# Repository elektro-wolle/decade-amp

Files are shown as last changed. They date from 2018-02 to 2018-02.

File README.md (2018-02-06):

# Selectable Decade Amplifier

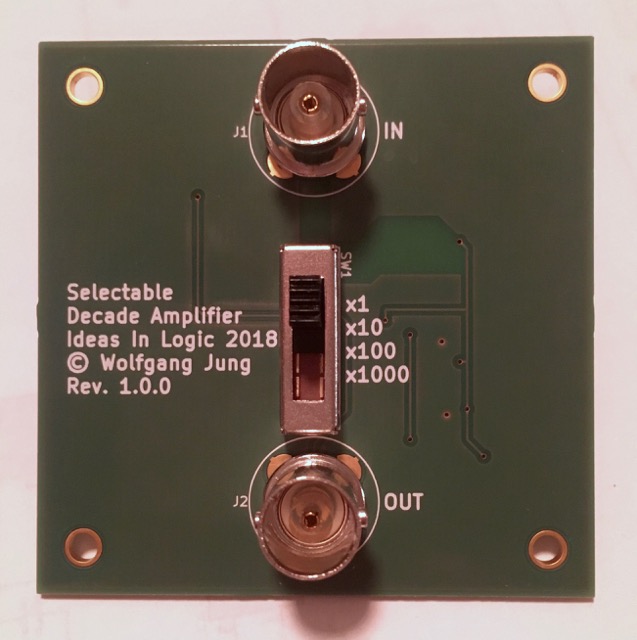
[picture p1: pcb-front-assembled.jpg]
Front


Due to my - in the highest sensitive ranges - a little bit noisy Rigol DS-1054z scope, I decided to provide a small pre-amplifier for low-voltage measurements (a.k.a. electret microphone signals, shunt-voltages, etc.).
For best performance in the micro-volt range, a dual stage amplifier (both stages provide 10V/1V gain) is built with the [MCP6V27](http://www.microchip.com/wwwproducts/en/MCP6V27). A third and last stage gives the final 10V/1V amplification resulting in a gain of 1000V/1V with a 3db cut-off at ~200 kHz.

For the third stage and the virtual ground a cheaper [MCP6292](http://www.microchip.com/wwwproducts/en/MCP6292) is used.

**The input voltage must not exceed ±1.5V!**

Current consumption should be ~1.6mA, the CR2032 coin-cell should last about 200h. The slide-switch disables the op-amps, if 1V/1V is selected.

Further improvements:
*  TVS-Diodes for clamping input voltage?

## Schematic
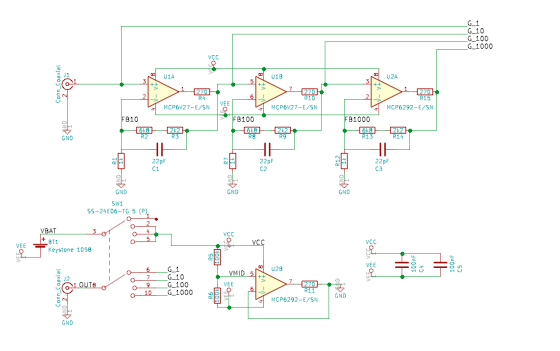
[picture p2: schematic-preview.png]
Schematic


### BOM

Ref|QTY|Value|Mouser
---|---|---|---
BT1|1|Keystone 1058|Keystone 1058
C1, C2, C3|3|22pF|885012007002
C4, C5|2|100nF|C0805C104K5RACTU
J1, J2|2|Conn_Coaxial|TE-5-1634503-1
R1, R7, R12|3|1k|RR1220P-102-D
R2, R8, R13|3|6k8|RR1220P-682-D
R3, R9, R14|3|2k2|RR1220P-222-D
R6, R5|2|100k|RR1220P-104-D
R11, R4, R10, R15|4|270R|RC0805JR-07270RL
SW1|1|SS-24E06-TG 5 (P)|SS-24E06-TG 5 (P)
U1|1|MCP6V27-E/SN|MCP6V27-E/SN
U2|1|MCP6292-E/SN|MCP6292-E/SN

## Final device

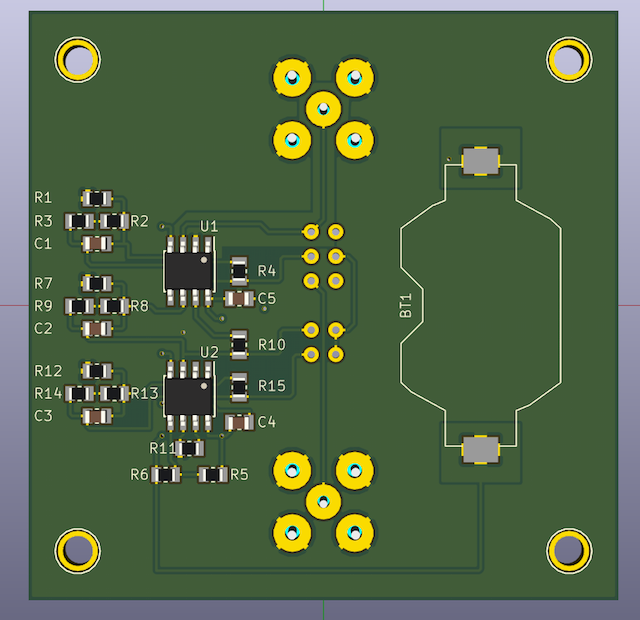
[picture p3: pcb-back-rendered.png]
Back (rendered)

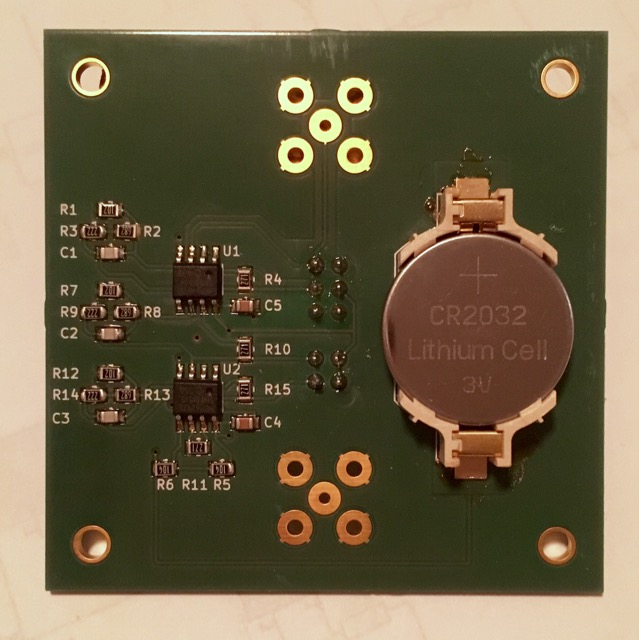
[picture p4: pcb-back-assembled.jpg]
Back


## Licence 
[Attribution-NonCommercial 4.0 International (CC BY-NC 4.0)](https://creativecommons.org/licenses/by-nc/4.0/) 2018 Wolfgang Jung, Ideas In Logic - Jung & Kesten GbR

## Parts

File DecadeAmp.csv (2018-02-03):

Source: | /Users/wolle/Documents/Hardware/flipdot/decadeAmp/DecadeAmp.sch
Date: | Samstag, 03. Februar 2018 'u23' 20:23:30
Tool: | Eeschema 4.0.7
Generator: | /Applications/Kicad/kicad.app/Contents/SharedSupport/plugins/bom_csv_grouped_by_value_with_fp.py
Component Count: | 26
Ref | Qnty | Value | Cmp name | Footprint | Description | Vendor
BT1, | 1 | Keystone 1058 | Battery_Cell | Battery_Holders:Keystone_1058_1x2032-CoinCell | single battery cell | Keystone 1058
C1, C2, C3, | 3 | 22pF | C | Capacitor_SMD:C_0805_2012Metric | Unpolarized capacitor | 885012007002
C4, C5, | 2 | 100nF | C | Capacitor_SMD:C_0805_2012Metric | Unpolarized capacitor | C0805C104K5RACTU
J1, J2, | 2 | Conn_Coaxial | Conn_Coaxial | Connector_Coaxial:BNC_TEConnectivity_1478204_Vertical | coaxial connector (BNC, SMA, SMB, SMC, Cinch/RCA, ...) | TE-5-1634503-1
R1, R7, R12, | 3 | 1k | R | Resistor_SMD:R_0805_2012Metric | Resistor | RR1220P-102-D
R2, R8, R13, | 3 | 6k8 | R | Resistor_SMD:R_0805_2012Metric | Resistor | RR1220P-682-D
R3, R9, R14, | 3 | 2k2 | R | Resistor_SMD:R_0805_2012Metric | Resistor | RR1220P-222-D
R6, R5, | 2 | 100k | R | Resistor_SMD:R_0805_2012Metric | Resistor | RR1220P-104-D
R11, R4, R10, R15, | 4 | 270 | R | Resistor_SMD:R_0805_2012Metric | Resistor | RC0805JR-07270RL
SW1, | 1 | SS-24E06-TG 5 (P) | SW_Slide2x4 | SS-24E06-TG5:SS-24E06-TG 5 (P) | 2 rotary switch with 6 positions | SS-24E06-TG 5 (P)
U1, | 1 | MCP6V27-E/SN | MCP6002-xSN | Package_SOIC:SOIC-8_3.9x4.9mm_P1.27mm | Dual Operational Amplifiers, DIP-8/SOIC-8/TSSOP-8/VSSOP-8 | MCP6V27-E/SN
U2, | 1 | MCP6292-E/SN | MCP6002-xSN | Package_SOIC:SOIC-8_3.9x4.9mm_P1.27mm | Dual Operational Amplifiers, DIP-8/SOIC-8/TSSOP-8/VSSOP-8 | MCP6292-E/SN

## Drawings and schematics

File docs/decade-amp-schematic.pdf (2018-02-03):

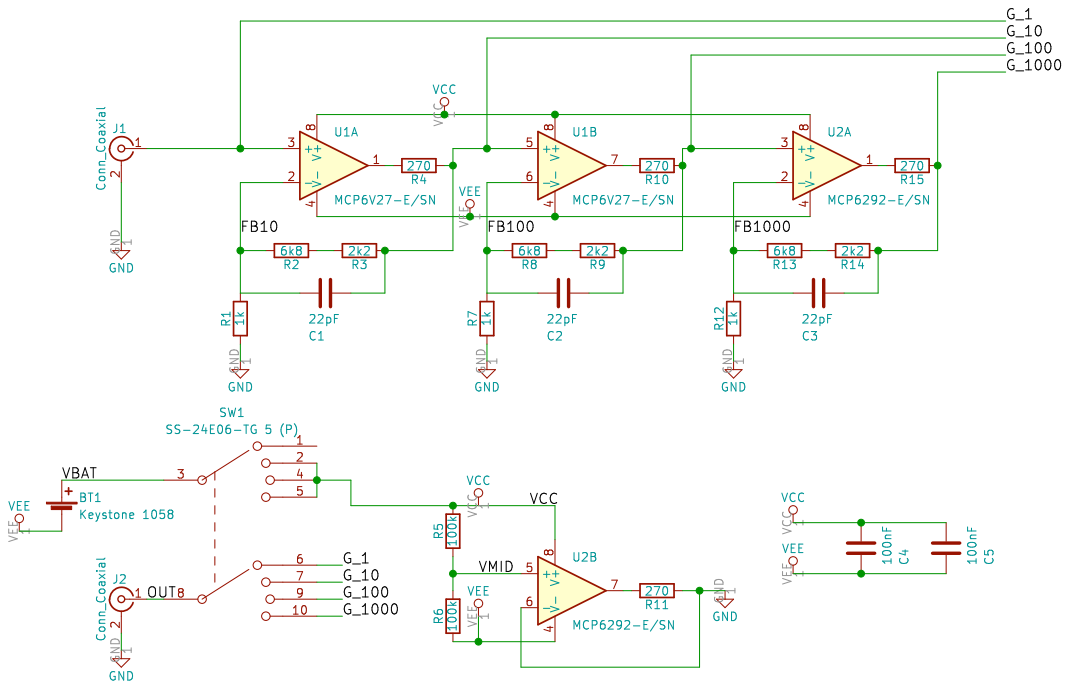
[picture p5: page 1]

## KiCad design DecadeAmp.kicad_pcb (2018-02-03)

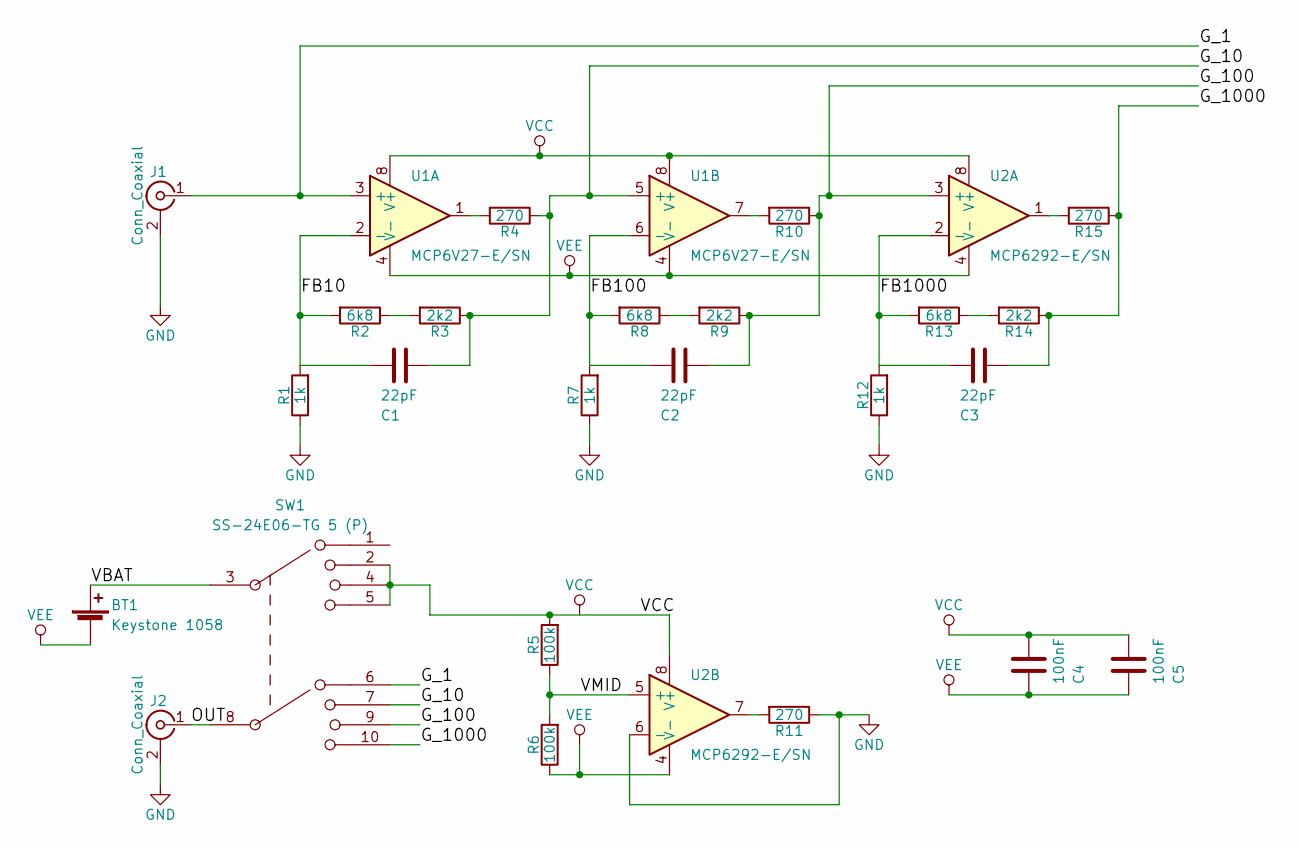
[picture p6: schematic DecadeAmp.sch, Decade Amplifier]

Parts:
BT1: Keystone 1058; Keystone_1058_1x2032-CoinCell
C1, C2, C3: 22pF; C_0805_2012Metric
C4, C5: 100nF; C_0805_2012Metric
J1, J2: Conn_Coaxial; BNC_TEConnectivity_1478204_Vertical
R1, R7, R12: 1k; R_0805_2012Metric
R2, R8, R13: 6k8; R_0805_2012Metric
R3, R9, R14: 2k2; R_0805_2012Metric
R4, R10, R11, R15: 270; R_0805_2012Metric
R5, R6: 100k; R_0805_2012Metric
SW1: SS-24E06-TG 5 (P)
U1: MCP6V27-E/SN; SOIC-8_3.9x4.9mm_P1.27mm
U2: MCP6292-E/SN; SOIC-8_3.9x4.9mm_P1.27mm

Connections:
/FB10: C1.2, R1.2, R2.2, U1.2 (-)
/FB100: C2.2, R7.2, R8.2, U1.6 (-)
/FB1000: C3.2, R12.2, R13.2, U2.2 (-)
/G_1: J1.1 (In), SW1.6, U1.3 (+)
/G_10: C1.1, R3.1, R4.1, SW1.7, U1.5 (+)
/G_100: C2.1, R9.1, R10.1, SW1.9, U2.3 (+)
/G_1000: C3.1, R14.1, R15.1, SW1.10
/OUT: J2.1 (In), SW1.8
/VBAT: BT1.1 (+), SW1.3
/VMID: R5.1, R6.2, U2.5 (+)
GND: J1.2 (Ext), J2.2 (Ext), R1.1, R7.1, R11.1, R12.1, U2.6 (-)
unnamed: R2.1, R3.2
unnamed: R4.2, U1.1
unnamed: R8.1, R9.2
unnamed: R10.2, U1.7
unnamed: R11.2, U2.7
unnamed: R13.1, R14.2
unnamed: R15.2, U2.1
VCC: C4.1, C5.1, R5.2, SW1.2, SW1.4, SW1.5, U1.8 (V+), U2.8 (V+)
VEE: BT1.2 (-), C4.2, C5.2, R6.1, U1.4 (V-), U2.4 (V-)

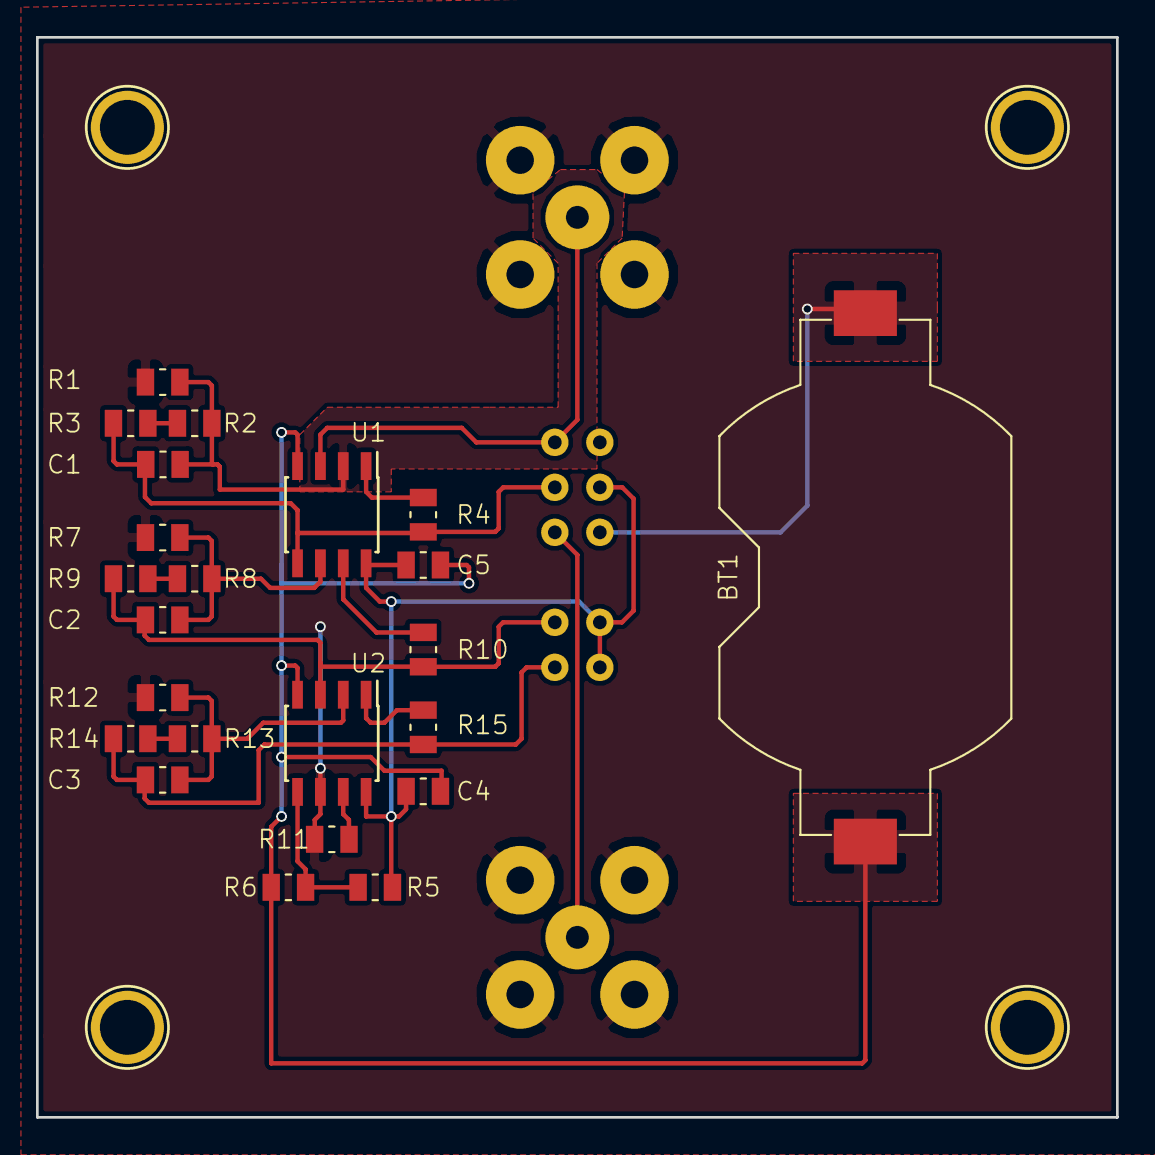
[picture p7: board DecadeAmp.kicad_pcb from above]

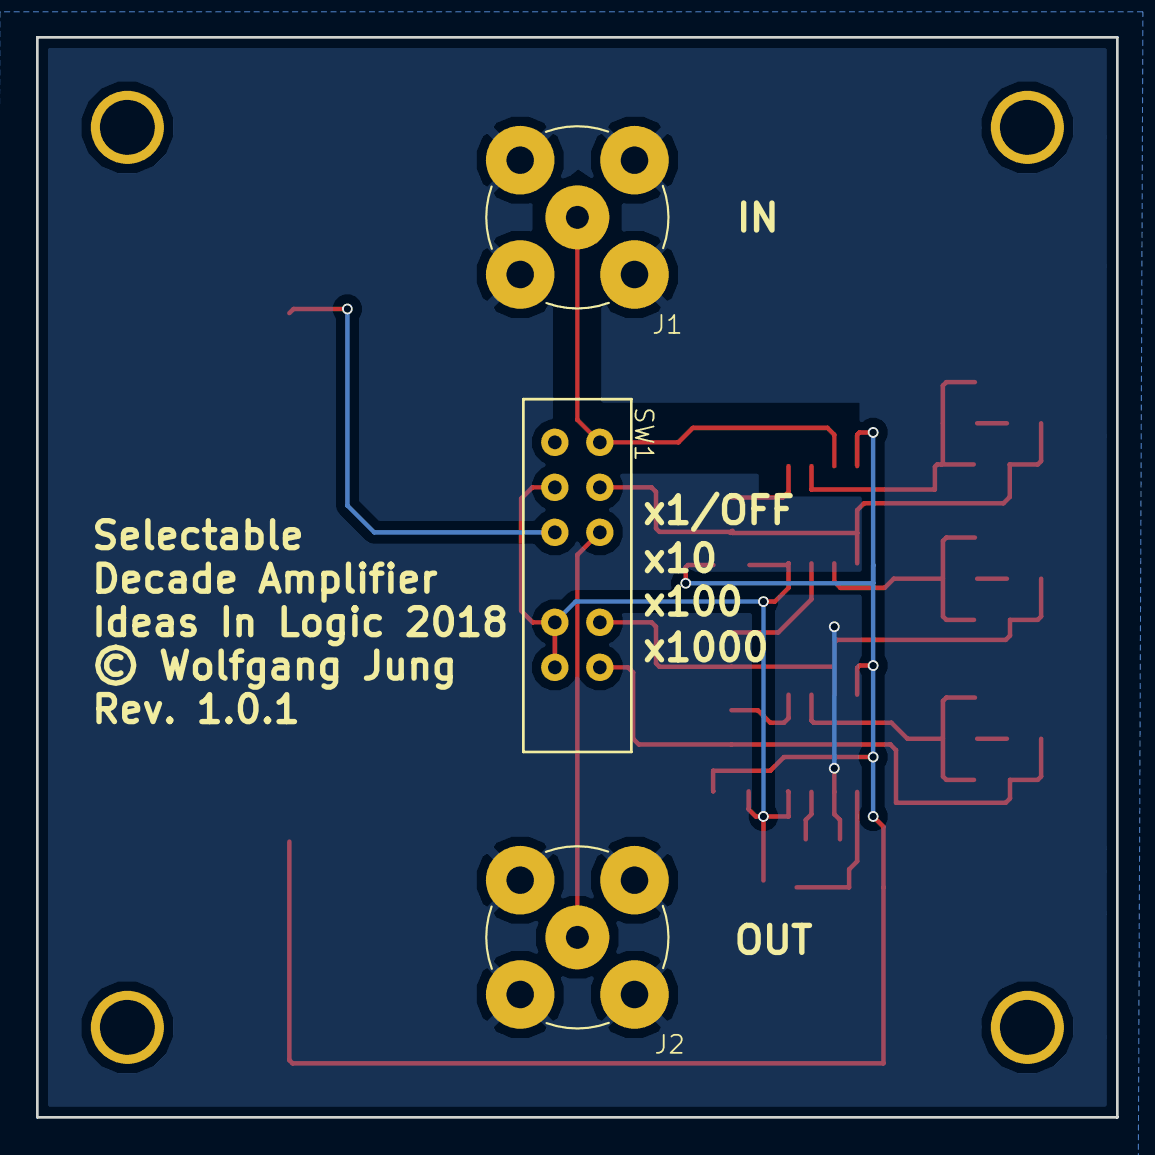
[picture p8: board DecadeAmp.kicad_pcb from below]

Board: 2 copper layers, 60.0 x 60.0 mm, 26 parts (3 on the bottom side), 20 nets.

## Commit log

2018-01-15 Initial version decade amp
    [DecadeAmp.kicad_pcb, DecadeAmp.sch]
2018-01-16 Correct Op-Amp MCP6292-E/SN
    [DecadeAmp.kicad_pcb, DecadeAmp.sch]
2018-01-16 Better fill
    [DecadeAmp.kicad_pcb]
2018-01-16 BOM added
    [DecadeAmp.csv]
2018-01-26 moved to new packages
    [DecadeAmp.kicad_pcb, DecadeAmp.sch]
2018-02-03 Better silkscreen, vendor-IDs of all components
    [DecadeAmp.csv, DecadeAmp.kicad_pcb, DecadeAmp.sch]

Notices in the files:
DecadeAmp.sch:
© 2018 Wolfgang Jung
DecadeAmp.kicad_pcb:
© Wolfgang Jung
